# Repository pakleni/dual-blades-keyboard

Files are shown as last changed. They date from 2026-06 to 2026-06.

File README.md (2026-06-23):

# Dual Blades



## Images
### Keyboard Layout
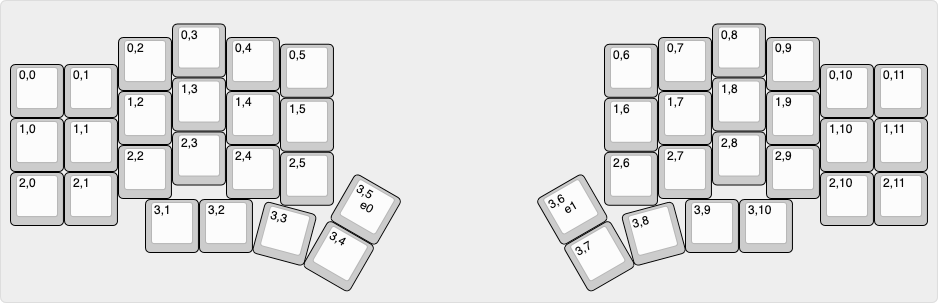
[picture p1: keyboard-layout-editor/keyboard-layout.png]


### Plates



### PCB
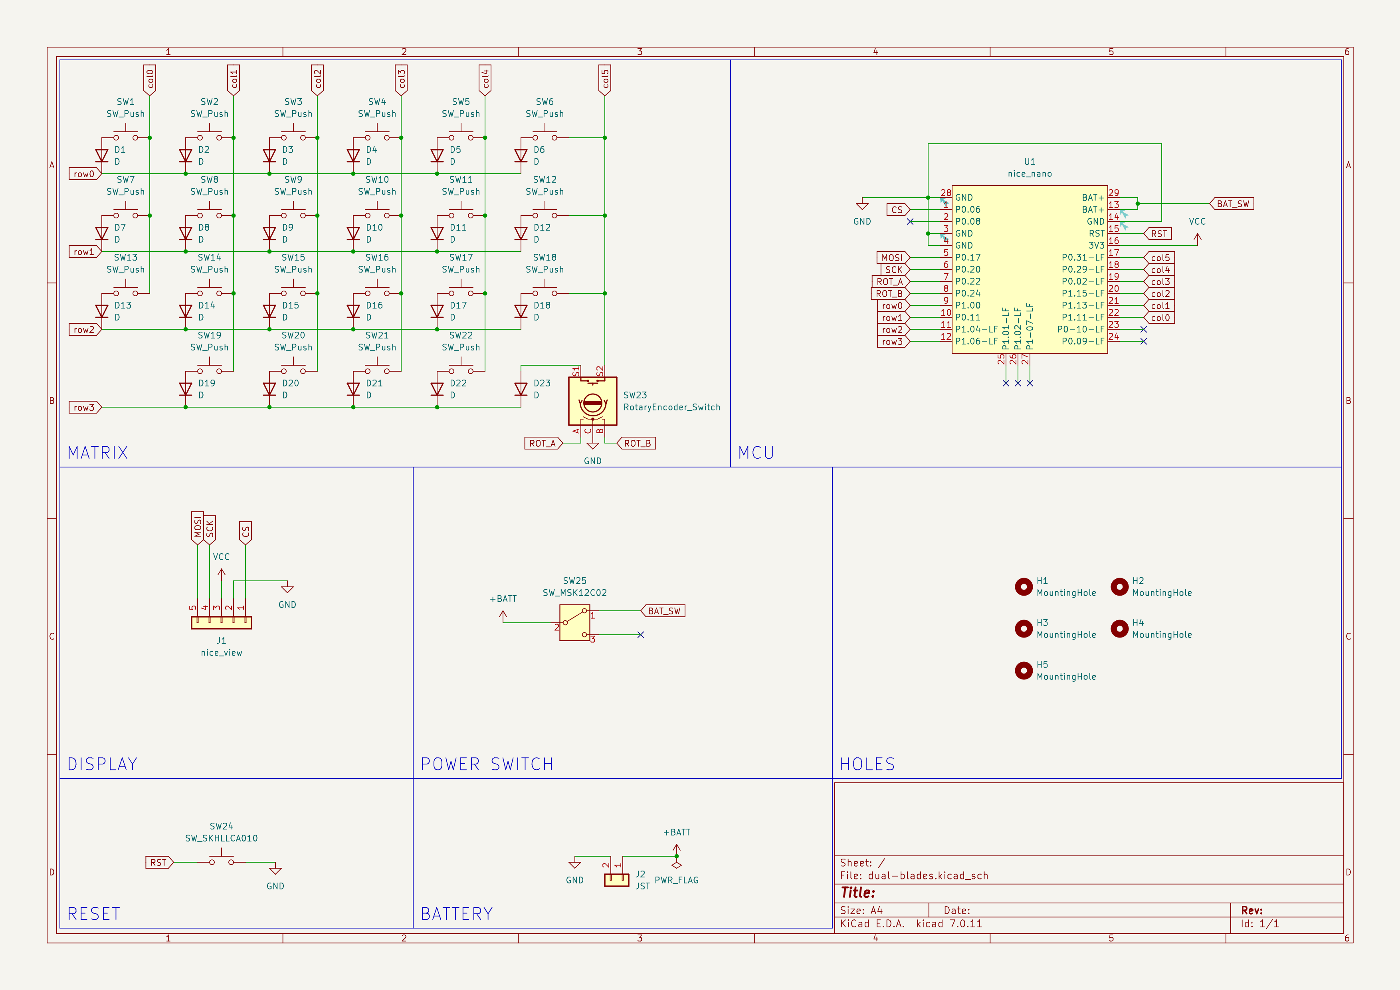
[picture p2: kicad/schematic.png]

<p float="left">
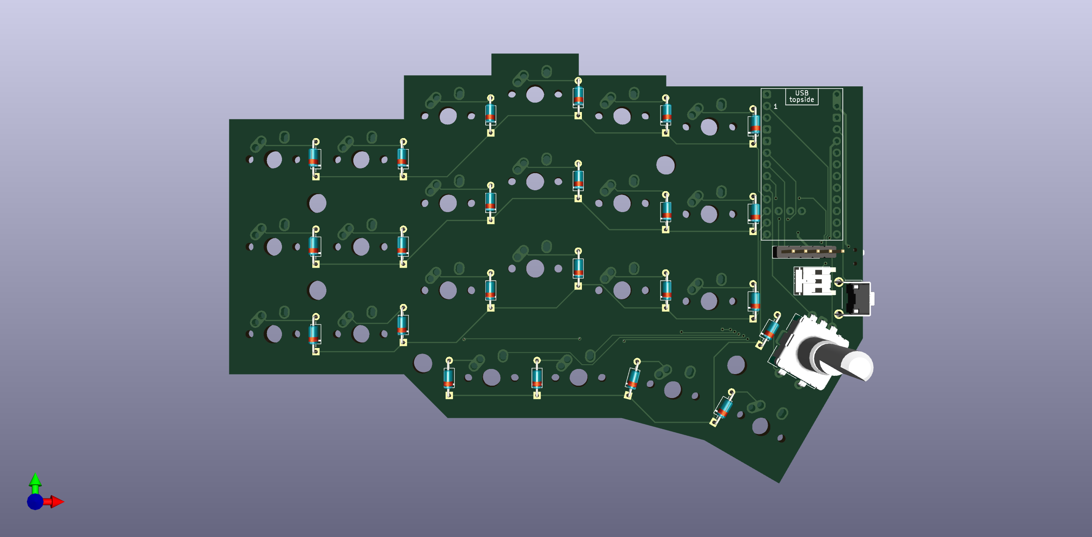
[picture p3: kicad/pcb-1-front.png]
  
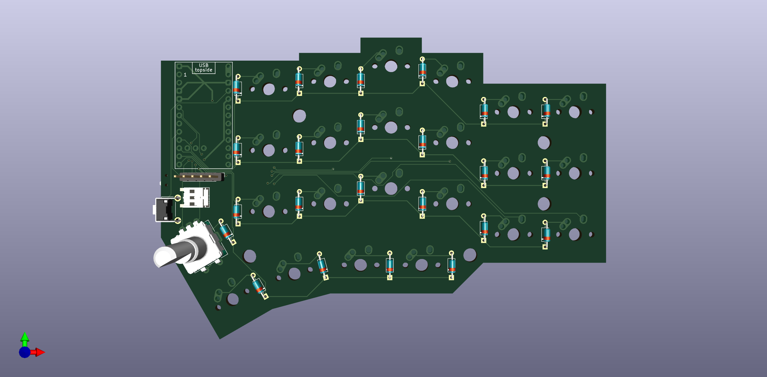
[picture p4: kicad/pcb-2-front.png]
  
</p>
<p float="left">
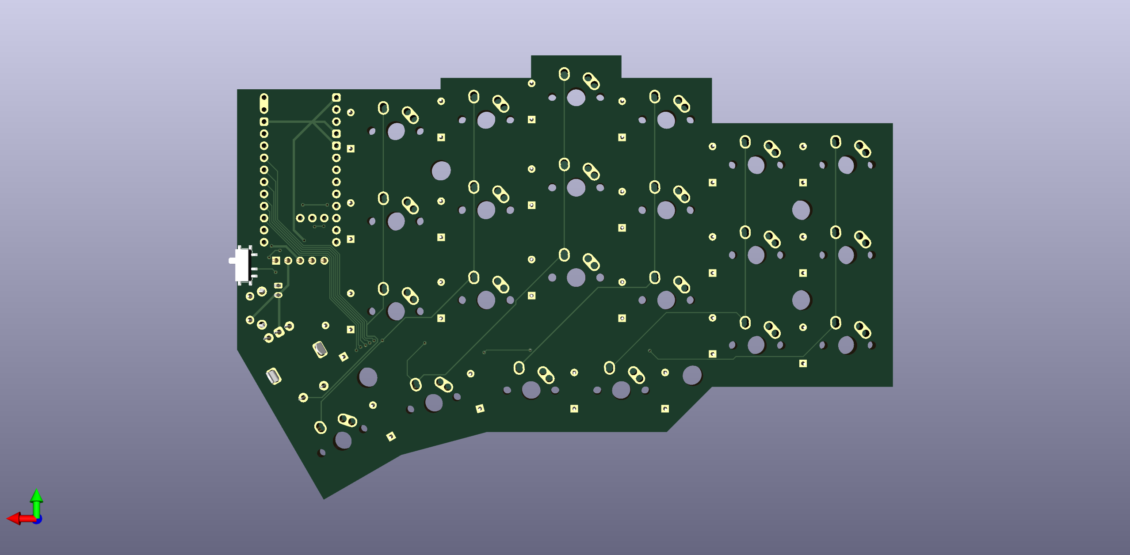
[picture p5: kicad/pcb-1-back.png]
  
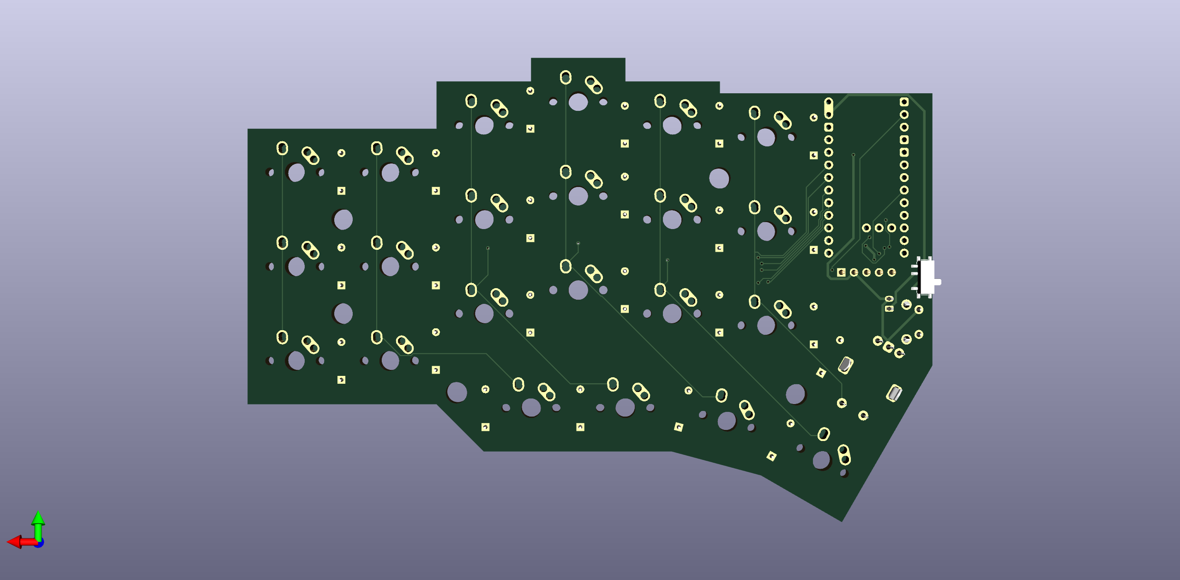
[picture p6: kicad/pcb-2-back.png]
  
</p>

## Features
* Split, wireless
* ZMK firmware
* nice!nano mcu
* nice!view display
* rotary encoders
* Column-staggered 44 key layout (inspired by the [Void Ergo S](https://github.com/victorlucachi/void_ergo))
* Switch-agnostic - hybrid MX/Alps PCB footprints + combo plate cutout
* Floating PCB plate
* LiPo batteries

## Firmware
[ZMK Keyboard Dual Blades](https://github.com/pakleni/zmk-keyboard-dual-blades)

## Bill of Materials

| Qty | Part |
|----:|---|
| 1 | [Matias Click Switch (box of 200)](https://matias.store/products/matias-click-switch-box-of-200) |
| 1 | [Keycap set - black blank Planck](https://matias.store/products/keycap-set-black-blank-planck) |
| 2 | [Encoder knobs](https://splitkb.com/products/knurled-metal-encoder-knob) |
| 2 | [nice!view](https://splitkb.com/products/nice-view) |
| 2 | [nice!nano](https://splitkb.com/products/nice-nano) |
| 1 | [Wireless Controller Expansion Bundle](https://splitkb.com/products/wireless-controller-expansion-bundle) |
| 1 | [THT 1N4148 diodes (100 pcs)](https://splitkb.com/products/tht-diodes) |
| 1 | [Linear rotary encoder](https://splitkb.com/products/linear-rotary-encoder) |
| 1 | [Tactile rotary encoder](https://splitkb.com/products/industrial-rotary-encoder) |
| 1 | [Reset buttons - **side push** (set of two)](https://splitkb.com/products/reset-buttons) |
| 2 | [Mill-Max Low Profile Sockets (with Headers)](https://splitkb.com/products/mill-max-low-profile-sockets) |
| 1 | [M2 screws - **4 mm**(set of 50)](https://splitkb.com/products/m2-screws) |
| 1 | [Brass M2 spacers - **8 mm** (set of 50)](https://splitkb.com/products/brass-m2-spacers) |
| 2 | [301230 LiPo (check polarity)](https://www.aliexpress.com/item/1005005348368664.html) |

## Used
* http://www.keyboard-layout-editor.com
* http://builder.swillkb.com
* https://librecad.org
* https://www.kicad.org



This work is licensed under a [Creative Commons Attribution-NonCommercial-ShareAlike 4.0 International License](https://creativecommons.org/licenses/by-nc-sa/4.0/).

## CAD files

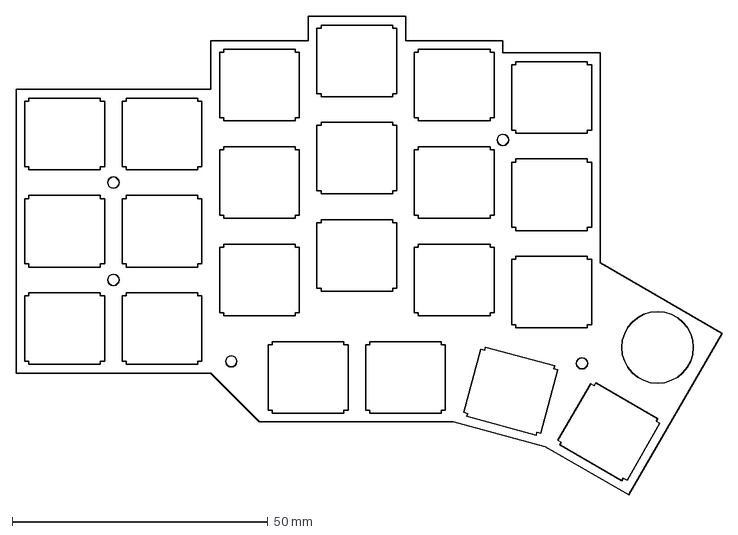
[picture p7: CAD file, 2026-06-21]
librecad/top-plate.dxf
138.1 x 93.6 mm

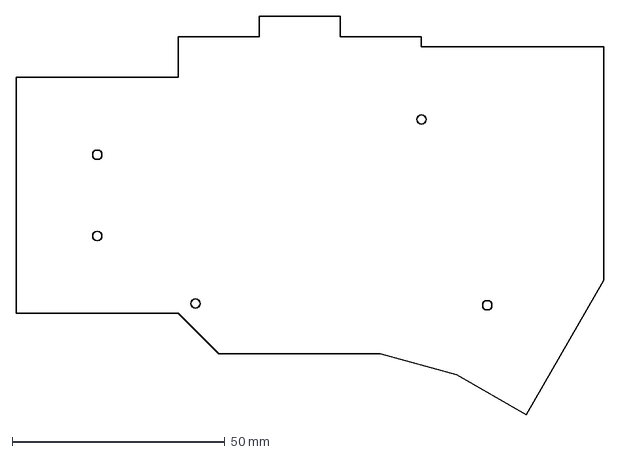
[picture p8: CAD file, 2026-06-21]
librecad/bottom-plate.dxf
138.1 x 93.6 mm

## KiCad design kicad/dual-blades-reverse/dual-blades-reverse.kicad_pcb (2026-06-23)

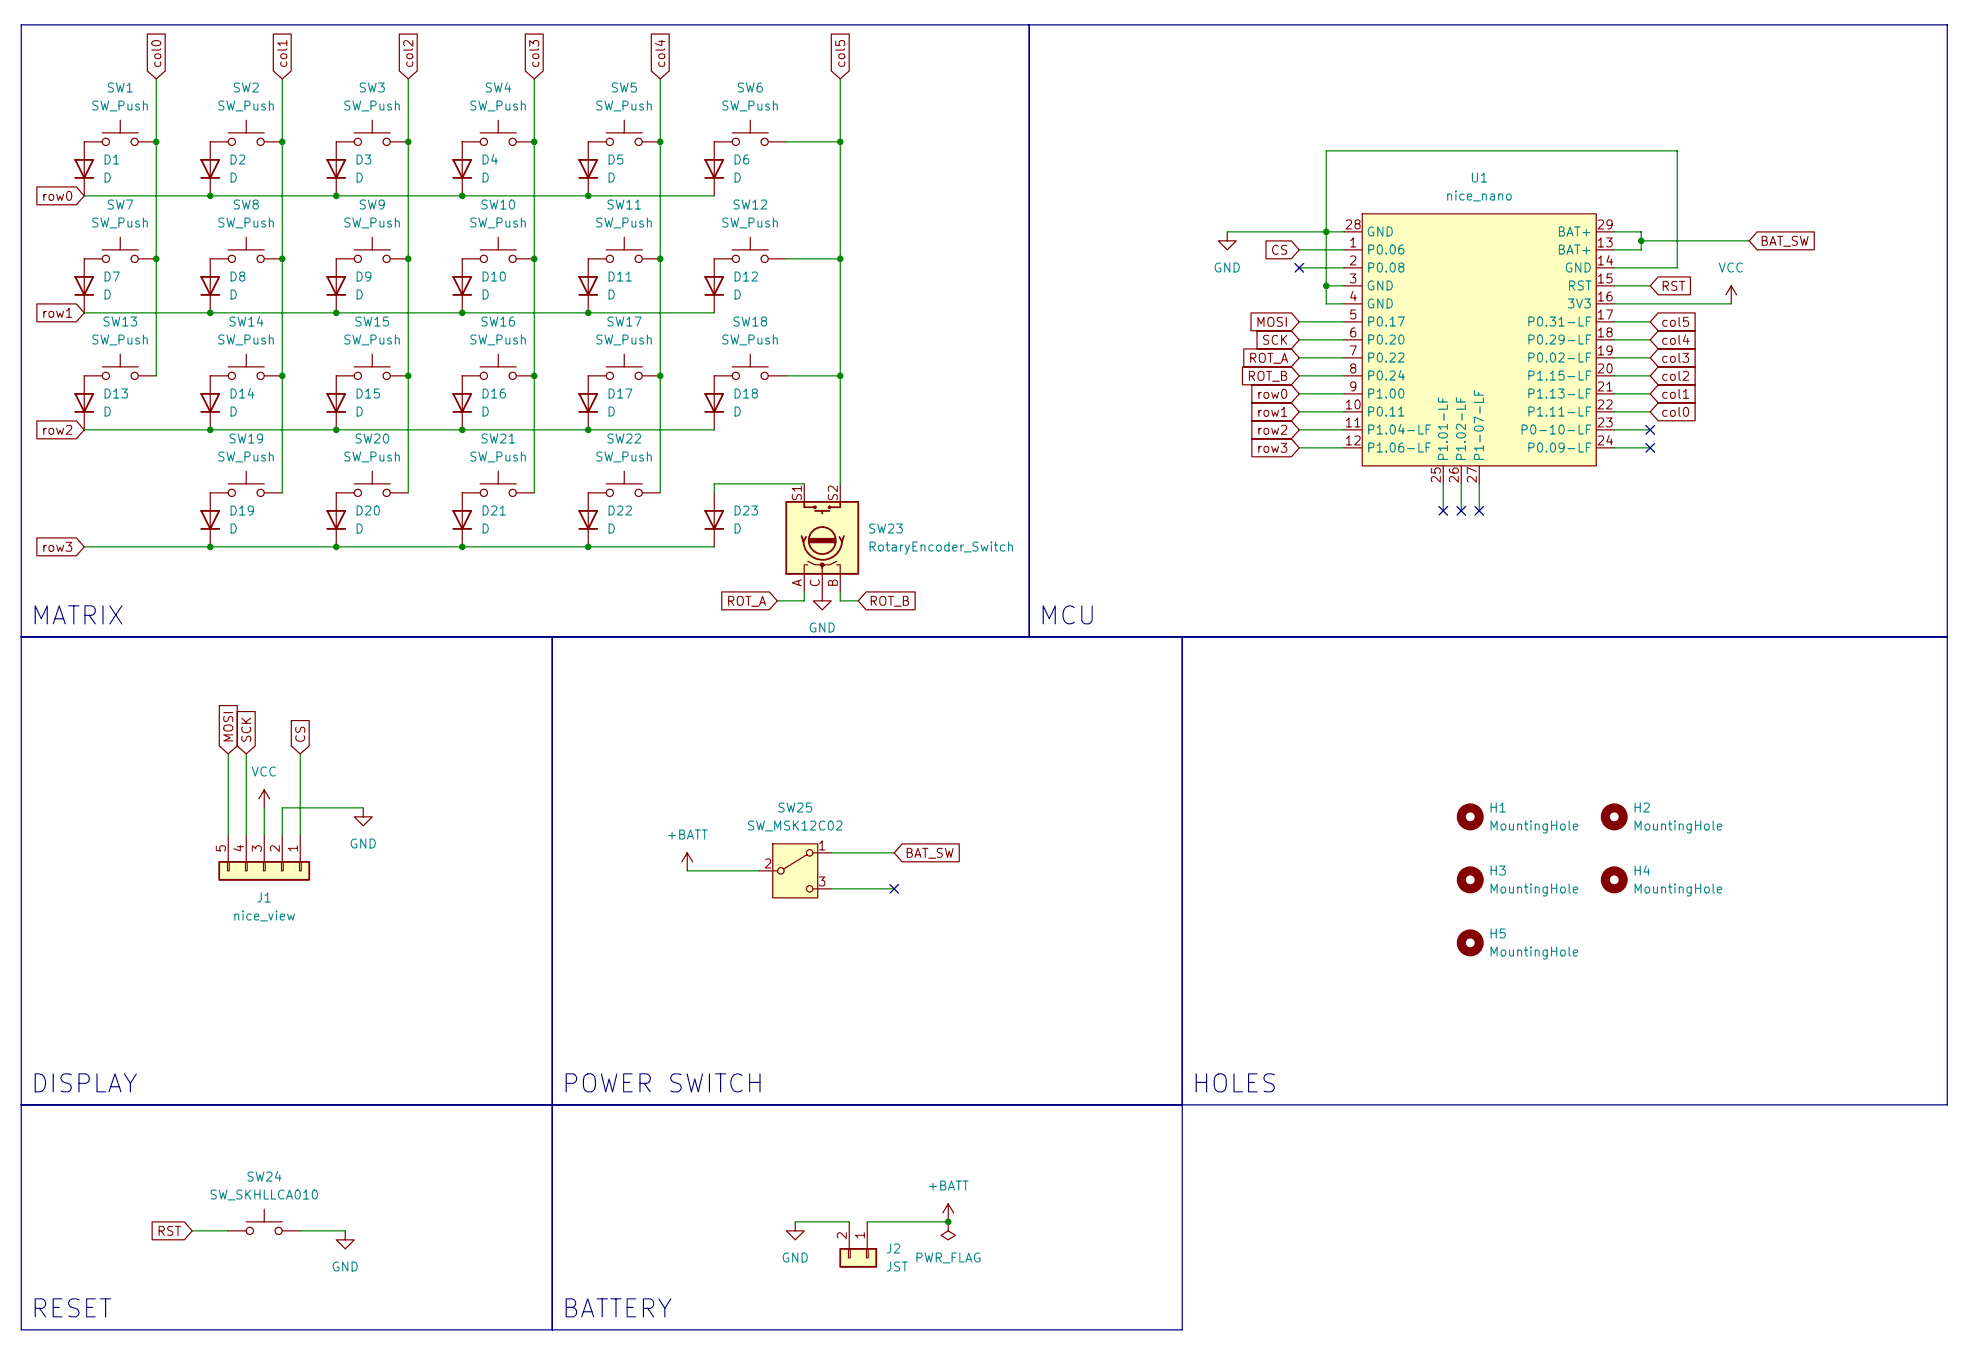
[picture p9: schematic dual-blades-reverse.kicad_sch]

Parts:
D1, D2, D3, D4, D5, D6, D7, D8, D9, D10, D11, D12, D13, D14, D15, D16, D17, D18, D19, D20, D21, D22, D23: D; D_DO-35_SOD27_P7.62mm_Horizontal
H1, H2, H3, H4, H5: MountingHole; MountingHole_4.3mm_M4
J1: nice_view; PinHeader_1x05_P2.54mm_Vertical
J2: JST; JST_PH_S2B-PH-K_1x02_P2.00mm_Horizontal
SW1, SW2, SW3, SW4, SW5, SW6, SW7, SW8, SW9, SW10, SW11, SW12, SW13, SW14, SW15, SW16, SW17, SW18, SW19, SW20, SW21, SW22: SW_Push; SW_Alps_MX_1u
SW23: RotaryEncoder_Switch; ROT_Alps_EC11E-Switch
SW24: SW_SKHLLCA010
SW25: SW_MSK12C02; SW_MSK12C02-HB
U1: nice_nano; nice_nano_AH_USBup

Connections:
+BATT: J2.1, SW25.2 (B)
BAT_SW: SW25.1 (A), U1.13 (BAT+), U1.29 (BAT+)
CS: J1.1, U1.1 (P0.06)
GND: J1.2, J2.2, SW23.C, SW24.2, U1.3 (GND), U1.4 (GND), U1.14 (GND), U1.28 (GND)
MOSI: J1.5, U1.5 (P0.17)
unnamed: D1.2 (A), SW1.1
unnamed: D2.2 (A), SW2.1
unnamed: D3.2 (A), SW3.1
unnamed: D4.2 (A), SW4.1
unnamed: D5.2 (A), SW5.1
unnamed: D6.2 (A), SW6.1
unnamed: D7.2 (A), SW7.1
unnamed: D8.2 (A), SW8.1
unnamed: D9.2 (A), SW9.1
unnamed: D10.2 (A), SW10.1
unnamed: D11.2 (A), SW11.1
unnamed: D12.2 (A), SW12.1
unnamed: D13.2 (A), SW13.1
unnamed: D14.2 (A), SW14.1
unnamed: D15.2 (A), SW15.1
unnamed: D16.2 (A), SW16.1
unnamed: D17.2 (A), SW17.1
unnamed: D18.2 (A), SW18.1
unnamed: D19.2 (A), SW19.1
unnamed: D20.2 (A), SW20.1
unnamed: D21.2 (A), SW21.1
unnamed: D22.2 (A), SW22.1
unnamed: D23.2 (A), SW23.S1
ROT_A: SW23.A, U1.7 (P0.22)
ROT_B: SW23.B, U1.8 (P0.24)
RST: SW24.1, U1.15 (RST)
SCK: J1.4, U1.6 (P0.20)
VCC: J1.3, U1.16 (3V3)
col0: SW1.2, SW7.2, SW13.2, U1.22 (P1.11-LF)
col1: SW2.2, SW8.2, SW14.2, SW19.2, U1.21 (P1.13-LF)
col2: SW3.2, SW9.2, SW15.2, SW20.2, U1.20 (P1.15-LF)
col3: SW4.2, SW10.2, SW16.2, SW21.2, U1.19 (P0.02-LF)
col4: SW5.2, SW11.2, SW17.2, SW22.2, U1.18 (P0.29-LF)
col5: SW6.2, SW12.2, SW18.2, SW23.S2, U1.17 (P0.31-LF)
row0: D1.1 (K), D2.1 (K), D3.1 (K), D4.1 (K), D5.1 (K), D6.1 (K), U1.9 (P1.00)
row1: D7.1 (K), D8.1 (K), D9.1 (K), D10.1 (K), D11.1 (K), D12.1 (K), U1.10 (P0.11)
row2: D13.1 (K), D14.1 (K), D15.1 (K), D16.1 (K), D17.1 (K), D18.1 (K), U1.11 (P1.04-LF)
row3: D19.1 (K), D20.1 (K), D21.1 (K), D22.1 (K), D23.1 (K), U1.12 (P1.06-LF)

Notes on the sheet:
HOLES
RESET
BATTERY
MATRIX
DISPLAY
POWER SWITCH
MCU

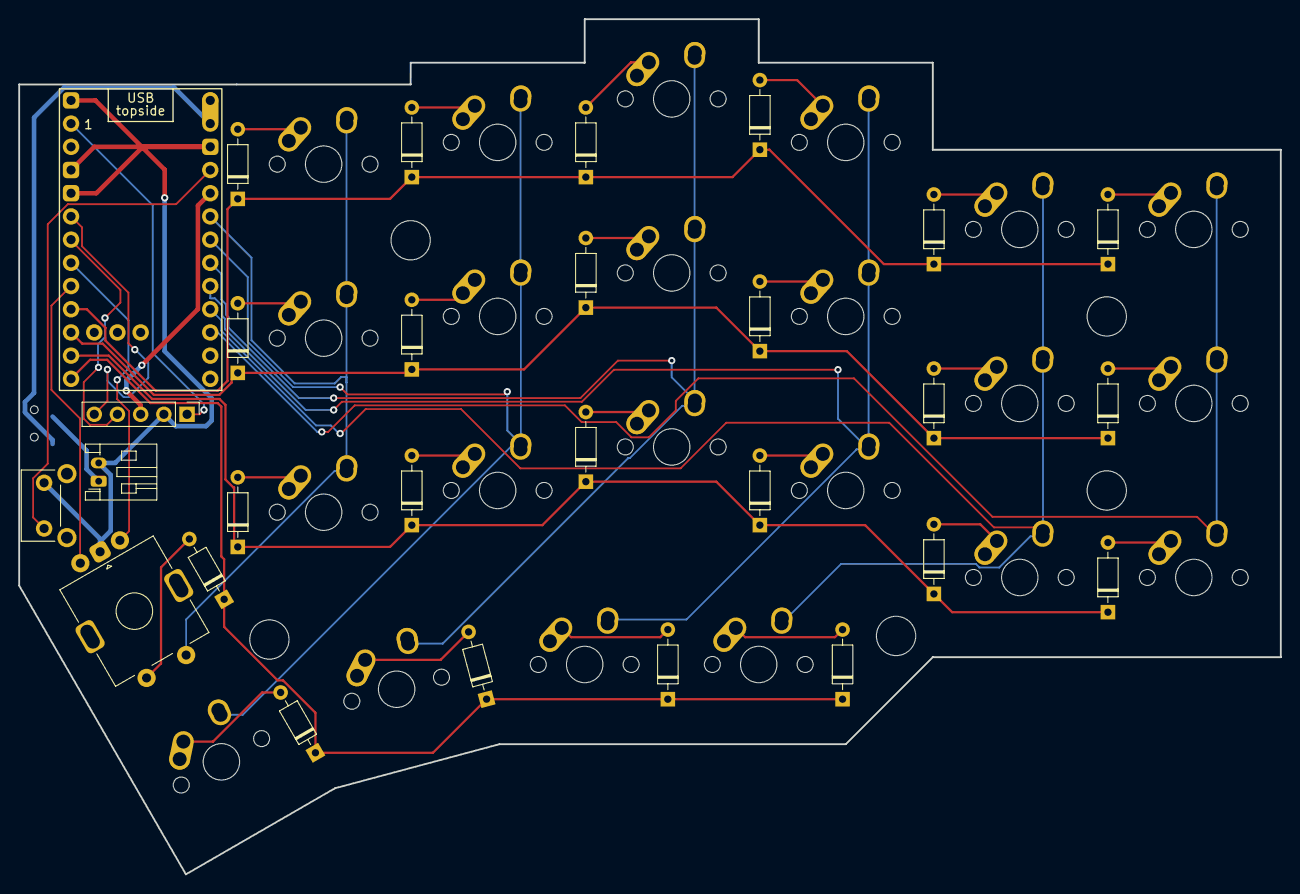
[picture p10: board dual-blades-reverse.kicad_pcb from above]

Board: 2 copper layers, 138.1 x 93.6 mm, 56 parts (1 on the bottom side), 43 nets.

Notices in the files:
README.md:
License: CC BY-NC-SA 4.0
